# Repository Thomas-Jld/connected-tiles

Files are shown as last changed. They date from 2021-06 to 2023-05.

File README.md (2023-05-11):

# Connected tiles

## Description

A set of square tiles that can be assembled to form a connected grid. The tiles can be used to create a board game to play tic-tac-toe, checkers, chess, or any other game that can be played on a square grid. A motherboard gathers information from the tiles and sends it to a computer via USB.

## Tiles

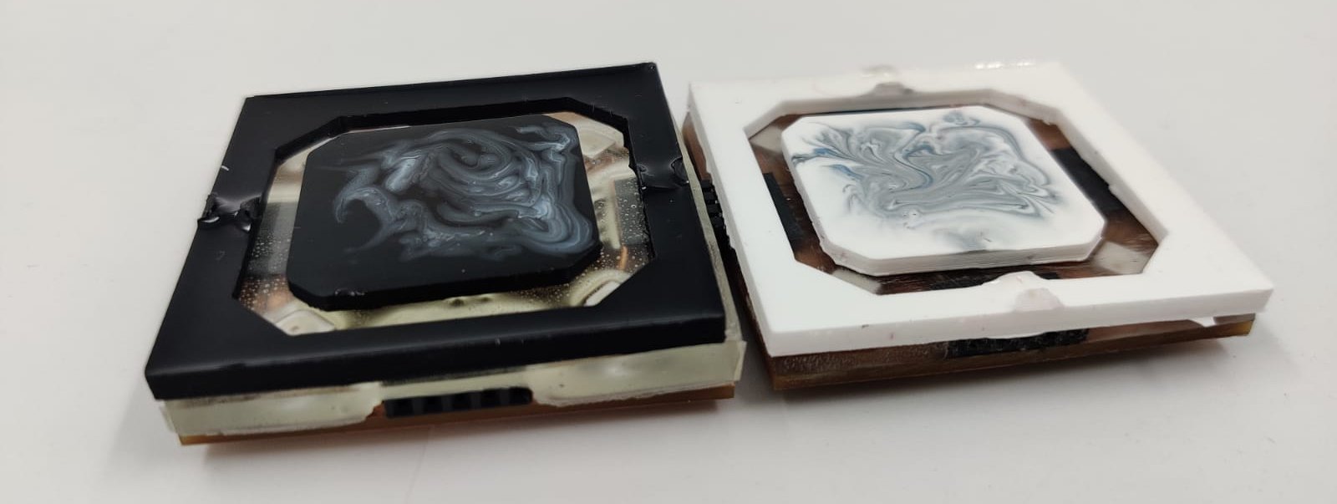
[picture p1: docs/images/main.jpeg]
cover


### Requirements

A tile must be able to:
- Connect to other tiles using a magnetic connection
- Know which tiles are connected to them and where the connected tile is located (**4 pins, 1 per direction**).
- Communicate with the motherboard via I2C (**8 pins, 2 per direction**).
- Receive power from the motherboard and power the connected tiles (**8 pins, 2 per direction**).
- Display an animation or a status color using Neopixels.
- Detect which piece is on top of it using a hall effect sensor.

### Piece detection

Sensing what piece was placed on top of the tile can be done in multiple ways:

**Currently used**

- 1D Hall effect sensor
- Color sensor
- Capacitive sensor

**Potential implementations**
- RFID
- 3D Hall effect sensor
- LC Resonance
- Weight sensor

### Components

**MCU**
- ATMEGA328PB-MU-ND [(1)](https://www.digikey.com/en/products/detail/microchip-technology/ATMEGA328PB-MU/5638814) [(2)](https://ww1.microchip.com/downloads/en/DeviceDoc/ATmega48A-PA-88A-PA-168A-PA-328-P-DS-DS40002061B.pdf)

Others:
- ATMEGA328P-AN [(1)](https://www.digikey.com/en/products/detail/microchip-technology/ATMEGA328P-AN/2357082)
- ATMEGA328-AU [(1)](https://www.digikey.com/en/products/detail/ATMEGA328-AU/ATMEGA328-AU-ND/2271029)

**Crystal**
- 20MHz 830108207209 CFPX-180 [(1)](https://www.digikey.com/en/products/detail/w%C3%BCrth-elektronik/830108207209/13900466)

Others:

- 20MHz HC49USM-FF3F18 [(1)](https://www.digikey.com/en/products/detail/ilsi/HC49USM-FF3F18-20-000MHZ/12619607)

**Neopixels**
- SK6812 [(1)](https://cdn-shop.adafruit.com/product-files/1138/SK6812+LED+datasheet+.pdf)

Others:

- WS2812B [(1)](https://cdn-shop.adafruit.com/datasheets/WS2812B.pdf)

**Hall effect sensor**
- DRV5053EA [(1)](https://www.digikey.com/en/products/detail/texas-instruments/DRV5053EAQDBZR/5015735)

Others:

- A1301 [(1)](https://media.digikey.com/pdf/Data%20Sheets/Allegro%20PDFs/A1301,02.pdf)
- DRV5056ZAQDBZR [(1)](https://www.mouser.fr/ProductDetail/Texas-Instruments/DRV5056Z4QDBZR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)

**Connection pins**
- Pogo pins [(1)](https://www.digikey.com/en/products/detail/mill-max-manufacturing-corp/829-22-020-20-002101/4007088) [(2)](https://www.mouser.com/ProductDetail/Mill-Max/854-22-003-20-001101?qs=XFe3dyCRgQjPe3AesOqKJA%3D%3D) [(3)](https://fr.aliexpress.com/item/1005003579709688.html) [(4)](https://www.digikey.com/en/products/detail/mill-max-manufacturing-corp/829-22-003-20-001101/2416224)

Others:

- U Shape Pin headers [(1)](https://www.wayconn.com/ph254-1u26/) [(2)](https://fr.aliexpress.com/i/32992671943.html) [(3)](https://www.digikey.com/en/products/detail/aries-electronics/16-675-191/4208672)

**Mating targets**
Magnet strength and Gauss calculator [here](https://www.kjmagnetics.com/calculator.asp)

- 399-10-164-10-008000 [(1)](https://www.digikey.com/en/products/detail/mill-max-manufacturing-corp/399-10-106-10-008000/4456257)

**Magnets**
- 8195 (6.35mm x 1.59mm) [(1)](https://www.digikey.com/en/products/detail/radial-magnets-inc/8195/555329)

Others:

- 5mm x 1mm neodymium magnets [(1)](https://www.magnetiques.fr/magnetique,aimant-rond-plat-552-fr.html)

**Reset tactile switch**
- TS04-66-43-BK-100-SMT [(1)](https://www.digikey.com/en/products/detail/cui-devices/TS04-66-43-BK-100-SMT/15634299)

**Capacitors**
- *Crystal:* 12pf 0603 0603N120J500CT [(1)](https://www.digikey.com/en/products/detail/walsin-technology-corporation/0603N120J500CT/9354977)
- *Hall effect sensor:* 12pf 0603 0603N120J500CT [(1)](https://www.digikey.com/en/products/detail/walsin-technology-corporation/0603N120J500CT/9354977)
- *Capacitive Touch:* 22nf 0402 C0402C223K5REC7411 [[1]](https://www.digikey.com/en/products/detail/kemet/C0402C223K5REC7411/8645043)

**LED**
- *Serial com* B1931UD--05D000314U1930 [(1)](https://www.digikey.com/en/products/detail/harvatek-corporation/B1931UD-05D000314U1930/15861266)
- *Color sensor (CS)* T2133BGR-20C0001U2U1930 [(1)](https://www.digikey.com/en/products/detail/harvatek-corporation/T2133BGR-20C0001U2U1930/17830297)

**Phototransistor**
- *Color sensor* B19H1PT--H9C000214U1930 [(1)](https://www.digikey.com/en/products/detail/harvatek-corporation/B19H1PT-H9C000214U1930/13574171)

**Resistors**
- *Neopixels:* 300 Ohm 0603 RC0603JR-07300RL [(1)](https://www.digikey.com/en/products/detail/yageo/RC0603JR-07300RL/726765)
- *Serial com led:* 300 Ohm 0603 RC0603JR-07300RL [(1)](https://www.digikey.com/en/products/detail/yageo/RC0603JR-07300RL/726765)
- *MCU Pull-up reset resistor:* 10k Ohm 0603 RC0603JR-071KL [(1)](https://www.digikey.com/en/products/detail/yageo/RC0603JR-0710KL/726700)
- *R channel of the CS RGB led:* 150 Ohm 0603 RC0603JR-07150RL [(1)](https://www.digikey.com/en/products/detail/yageo/RC0603JR-07150RL/726714)
- *G channel of the CS RGB led:* 90 Ohm 0603 RC0603JR-0791RL [(1)](https://www.digikey.com/en/products/detail/yageo/RC0603JR-0791RL/726840)
- *B channel of the CS RGB led:* 90 Ohm 0603 RC0603JR-0791RL [(1)](https://www.digikey.com/en/products/detail/yageo/RC0603JR-0791RL/726840)
- *Capacitive touch:* 1k Ohm 0603 RC0603JR-071KL [(1)](https://www.digikey.com/en/products/detail/yageo/RC0603JR-071KL/726677)

### Tile detection mechanism

When the tiles are powered up, their "connection" pins are set as Outputs and are set to HIGH...

### Pieces

A piece category is defined by the magnetic field it generates. For example, in chess, the pieces are:
- Pawn: 1 magnet
- Rook: 2 magnets
- Knight: 3 magnets
- Bishop: 4 magnets
- Queen: 5 magnets
- King: 6 magnets

## Motherboard

### Requirements

The motherboard should be able to:
- Power up to 64 tiles, each tile consuming up to 250mA (16A total).
- Communicate with each tile using I2C:
  The added capacitance of each tile could be a problem (regular I2C is limited to 400pF), which means that the bus will either need to be slowed down or an extender will be placed on the motherboard (the [LTC4311](https://www.adafruit.com/product/4756) allows the bus coupling capacitance to be up to 4000pF)
- Communicate with the computer using USB or operate autonomously.

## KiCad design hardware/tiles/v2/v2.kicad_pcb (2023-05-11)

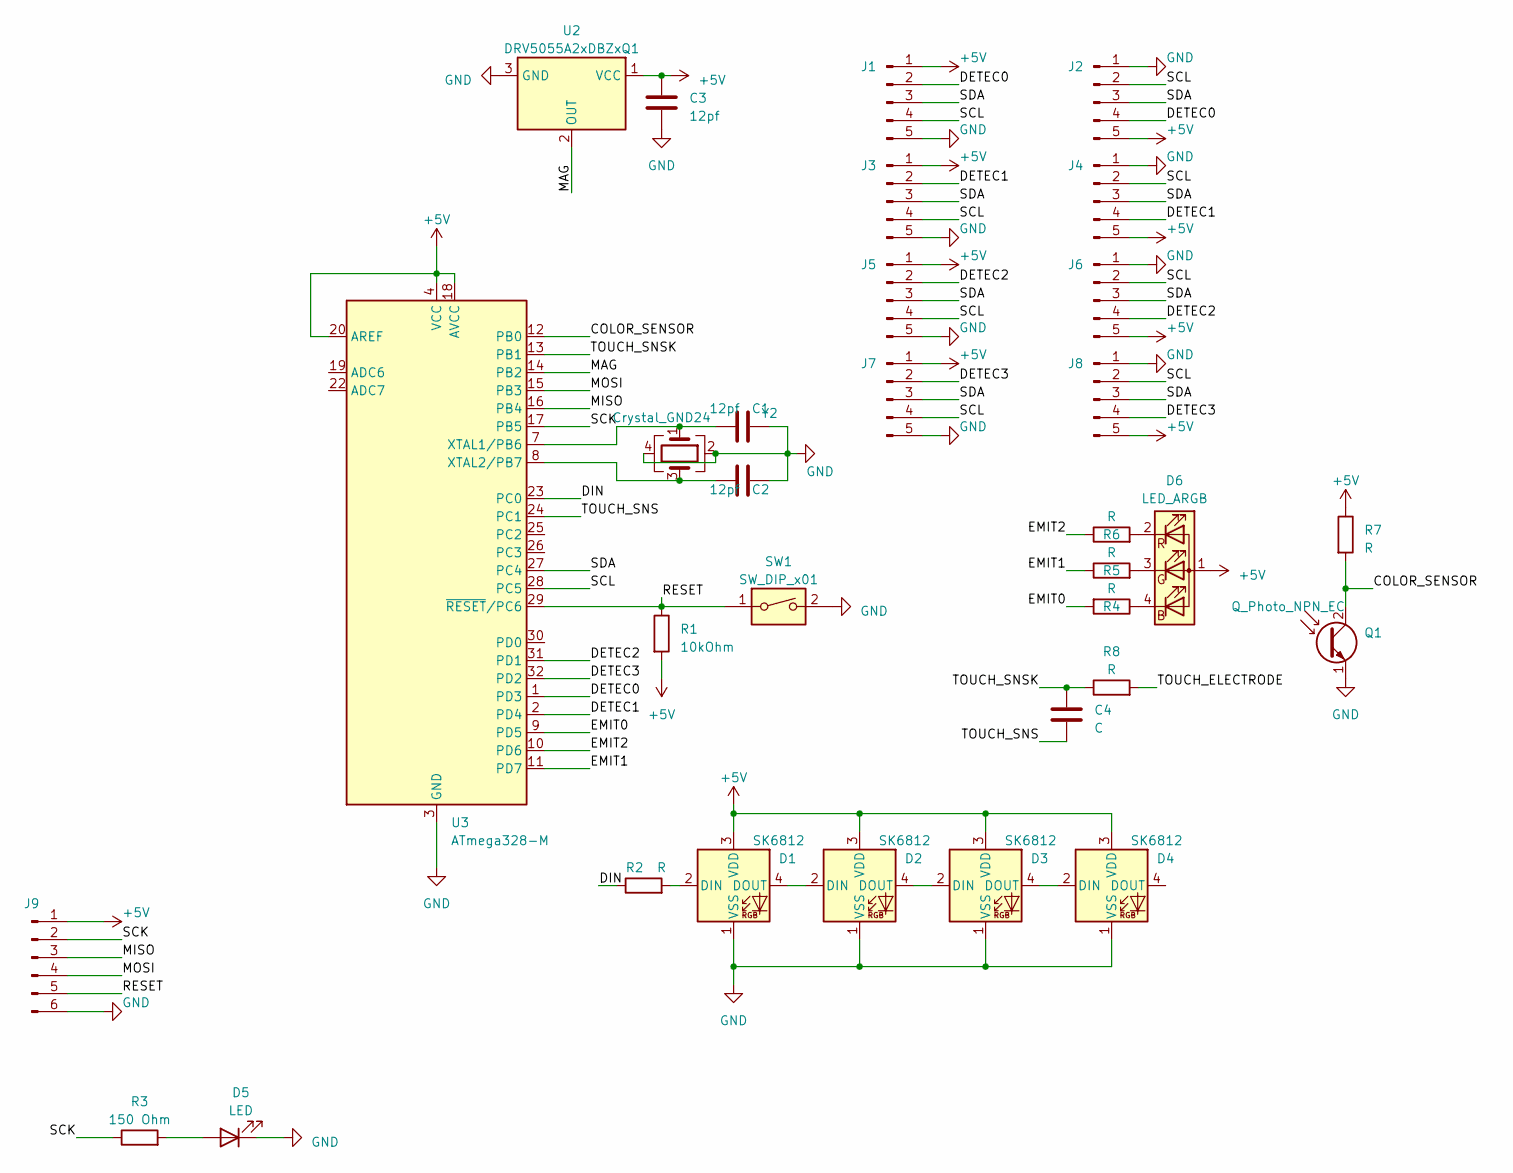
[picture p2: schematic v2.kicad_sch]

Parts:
C1, C2, C3: 12pf; C_0603_1608Metric_Pad1.08x0.95mm_HandSolder
C4: C; C_0402_1005Metric_Pad0.74x0.62mm_HandSolder
D1, D2, D3, D4: SK6812; LED_SK6812_PLCC4_5.0x5.0mm_P3.2mm
D5: LED; LED_0603_1608Metric_Pad1.05x0.95mm_HandSolder
D6: LED_ARGB; LED_WS2812B-2020_PLCC4_2.0x2.0mm
J1, J2, J3, J4, J5, J6, J7, J8: Conn_01x05_Pin; PinHeader_1x05_P2.54mm_Horizontal
J9: Conn_01x06_Pin; PinHeader_1x06_P2.54mm_Vertical
Q1: Q_Photo_NPN_EC; R_0603_1608Metric_Pad0.98x0.95mm_HandSolder
R1: 10kOhm; R_0603_1608Metric_Pad0.98x0.95mm_HandSolder
R2, R4, R5, R6, R7, R8: R; R_0603_1608Metric_Pad0.98x0.95mm_HandSolder
R3: 150 Ohm; R_0603_1608Metric_Pad0.98x0.95mm_HandSolder
SW1: SW_DIP_x01; SW_SPST_PTS645
U2: DRV5055A2xDBZxQ1; SOT-23
U3: ATmega328-M; QFN-32-1EP_5x5mm_P0.5mm_EP3.1x3.1mm
Y2: Crystal_GND24; Crystal_SMD_3225-4Pin_3.2x2.5mm_HandSoldering

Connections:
+5V: C3.1, D1.3 (VDD), D2.3 (VDD), D3.3 (VDD), D4.3 (VDD), D6.1 (A), J1.1, J2.5, J3.1, J4.5, J5.1, J6.5, J7.1, J8.5, J9.1, R1.2, R7.1, U2.1 (VCC), U3.4 (VCC), U3.6 (VCC), U3.18 (AVCC), U3.20 (AREF)
/COLOR_SENSOR: Q1.2 (C), R7.2, U3.12 (PB0)
/DETEC0: J1.2, J2.4, U3.1 (PD3)
/DETEC1: J3.2, J4.4, U3.2 (PD4)
/DETEC2: J5.2, J6.4, U3.31 (PD1)
/DETEC3: J7.2, J8.4, U3.32 (PD2)
/DIN: R2.1, U3.23 (PC0)
/EMIT0: R4.2, U3.9 (PD5)
/EMIT1: R5.1, U3.11 (PD7)
/EMIT2: R6.1, U3.10 (PD6)
/MAG: U2.2 (OUT), U3.14 (PB2)
/MISO: J9.3, U3.16 (PB4)
/MOSI: J9.4, U3.15 (PB3)
/RESET: J9.5, R1.1, SW1.1, U3.29 (~RESET/PC6)
/SCK: J9.2, R3.1, U3.17 (PB5)
/SCL: J1.4, J2.2, J3.4, J4.2, J5.4, J6.2, J7.4, J8.2, U3.28 (PC5)
/SDA: J1.3, J2.3, J3.3, J4.3, J5.3, J6.3, J7.3, J8.3, U3.27 (PC4)
/TOUCH_ELECTRODE: R8.2
/TOUCH_SNS: C4.2, U3.24 (PC1)
/TOUCH_SNSK: C4.1, R8.1, U3.13 (PB1)
GND: C1.2, C2.2, C3.2, D1.1 (VSS), D2.1 (VSS), D3.1 (VSS), D4.1 (VSS), D5.1 (K), J1.5, J2.1, J3.5, J4.1, J5.5, J6.1, J7.5, J8.1, J9.6, Q1.1 (E), SW1.2, U2.3 (GND), U3.3 (GND), U3.5 (GND), U3.21 (GND), U3.33 (GND), Y2.2, Y2.4
unnamed: D1.2 (DIN), R2.2
unnamed: D1.4 (DOUT), D2.2 (DIN)
unnamed: D2.4 (DOUT), D3.2 (DIN)
unnamed: D3.4 (DOUT), D4.2 (DIN)
unnamed: D5.2 (A), R3.2
unnamed: D6.4 (BK), R4.1
unnamed: D6.3 (GK), R5.2
unnamed: D6.2 (RK), R6.2
unnamed: C1.1, U3.7 (XTAL1/PB6), Y2.1
unnamed: C2.1, U3.8 (XTAL2/PB7), Y2.3

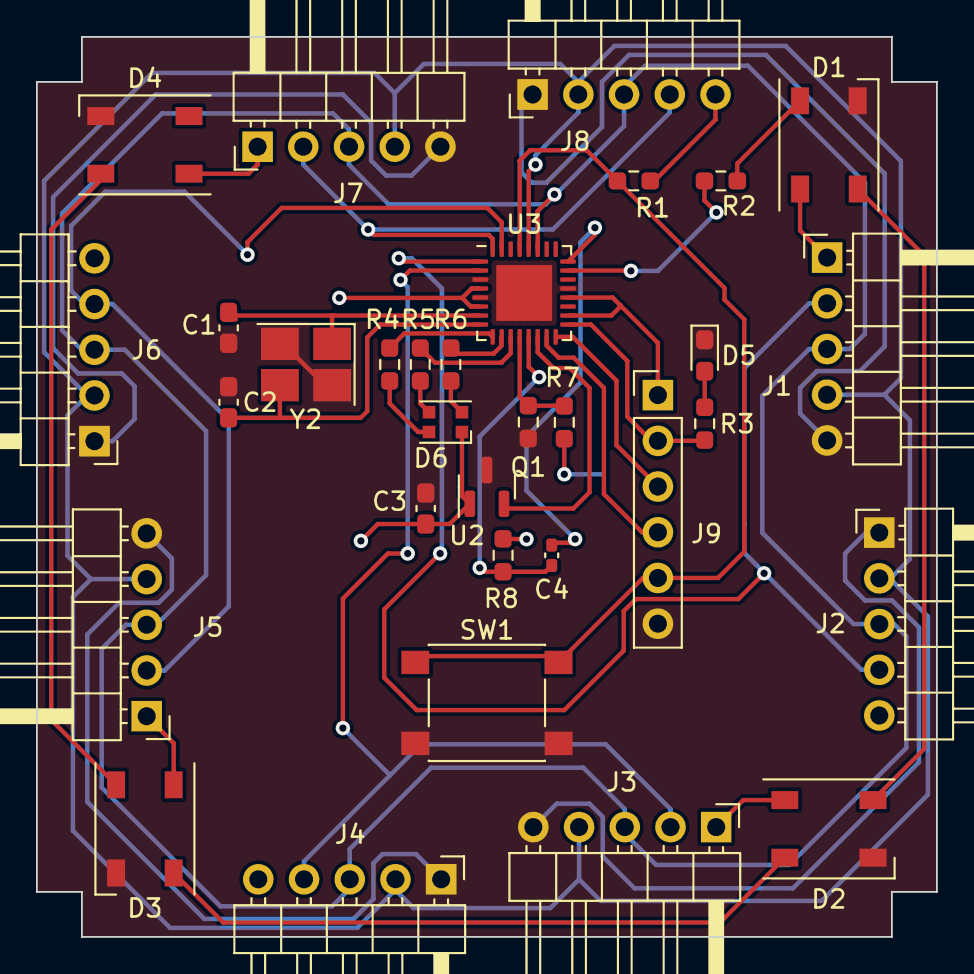
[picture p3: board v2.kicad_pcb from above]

Board: 2 copper layers, 50.0 x 50.0 mm, 32 parts (0 on the bottom side), 30 nets.

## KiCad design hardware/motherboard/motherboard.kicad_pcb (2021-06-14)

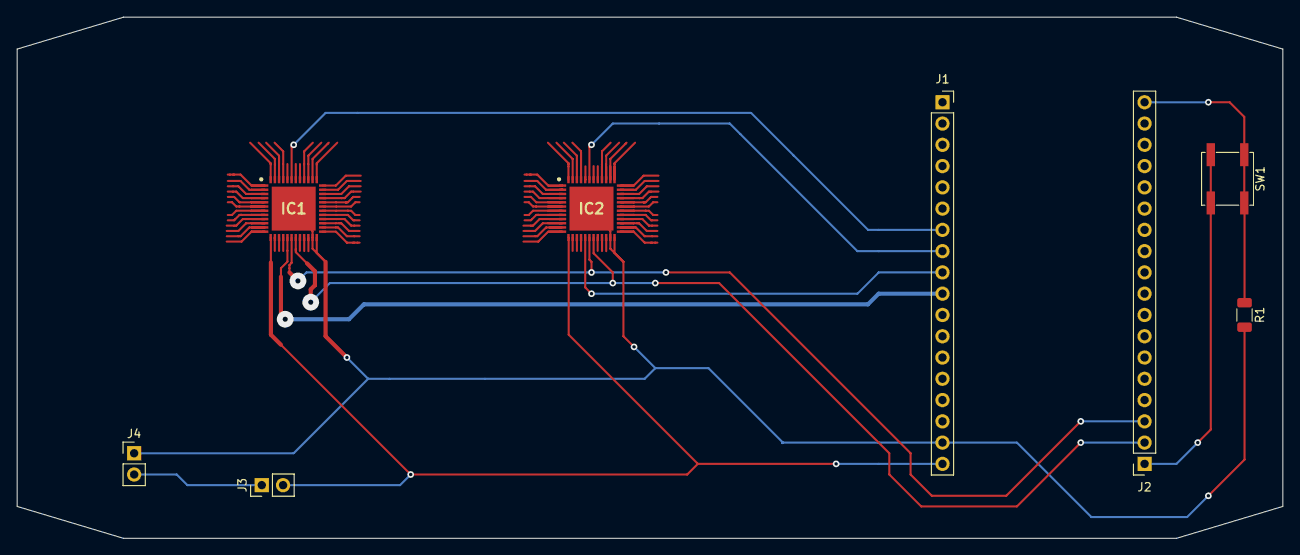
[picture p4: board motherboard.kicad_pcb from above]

Board: 2 copper layers, 151.1 x 62.2 mm, 8 parts (0 on the bottom side), 11 nets.

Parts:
IC1, IC2: ADG731BCPZ; QFN50P700X700X100-49N-D
J1, J2: Conn_01x18_Female; PinSocket_1x18_P2.54mm_Vertical
J3, J4: Conn_01x02_Female; PinHeader_1x02_P2.54mm_Vertical
R1: R; R_1206_3216Metric
SW1: SW_Push; SW_SPST_EVPBF

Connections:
+5V: IC1.13, IC2.13, J1.18, J3.2
DATA1: IC1.43, J1.7
DATA2: IC2.43, J1.8
DIN: IC1.18, IC2.18, J2.3
GNDREF: IC1.23, IC1.24, IC1.49, IC2.23, IC2.24, IC2.49, J1.17, J4.1, R1.2
unnamed: J2.1, SW1.2
unnamed: J2.18, R1.1, SW1.1
unnamed: J3.1, J4.2
SCLK: IC1.19, IC2.19, J2.2
SYNC1: IC1.17, J1.10
SYNC2: IC2.17, J1.9

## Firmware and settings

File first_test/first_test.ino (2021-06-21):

#include <Adafruit_NeoPixel.h>
#ifdef __AVR__
 #include <avr/power.h> // Required for 16 MHz Adafruit Trinket
#endif

#define PIN        6
#define NUMPIXELS 60
Adafruit_NeoPixel pixels(NUMPIXELS, PIN, NEO_GRB + NEO_KHZ800);

#define DELAYVAL 0.01

float fact = 0.5;
int counter = 0;
//int path[] = {0, 1, 2, 4, 7, 6, 5, 3, };
//int path[] = {0, 1, 2, 5, 6, 7, 4, 3, };

void setup() {
  Serial.begin(9600);
  pixels.begin();}

void loop() {
  counter+=5;
  if(counter> 360*20){
    counter = 0;
  }
  for(int i=0; i<NUMPIXELS; i++) { 
    fact = dist(float(i)/NUMPIXELS, counter%360) ;
    //* fade(counter/3.);
    pixels.setPixelColor(i, pixels.Color(255 * fact, 255 * fact, 255 * fact));
    //pixels.setPixelColor(path[i], pixels.Color(255 * fact, 255 * fact, 255 * fact));
  }
    delay(DELAYVAL); // Pause before next pass through loop
    pixels.show();   // Send the updated pixel colors to the hardware.
    Serial.println(fact);
}

float fade(float counter){
  return (sin(2.0*3.14*counter/360.0) + 1)/2.0;
}

float dist(float i, int counter){
  int a = min(i*360, counter);
  int b = max(i*360, counter);
  int d = min(b-a, 360-b + a);
  return min(0.05 + 0.95*pow(d / 180.0, 4), 1);
}

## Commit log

2021-06-14 Adding tiles
    [connected_tiles-B_Cu.gbr, connected_tiles-Edge_Cuts.gbr, connected_tiles-F_Cu.gbr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]
2021-06-14 Adding Kicad project files
    [tiles.kicad_pcb, tiles.sch]
2021-06-14 moved project
    [motherboard.kicad_pcb, motherboard.sch]
2023-05-08 Pcb hardware update
    [motherboard.kicad_pcb, motherboard.sch, tiles.kicad_pcb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]
2023-05-11 Updating PCB with Capacitive touch and Color sensor
    [v2.kicad_pcb, v2.kicad_sch]
